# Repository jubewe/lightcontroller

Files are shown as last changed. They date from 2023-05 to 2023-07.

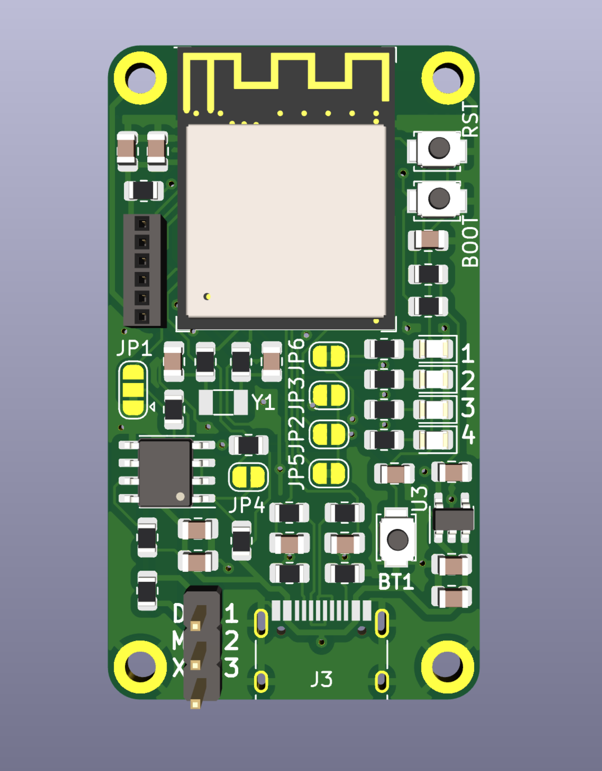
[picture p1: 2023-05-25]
pcb/pcb1.png

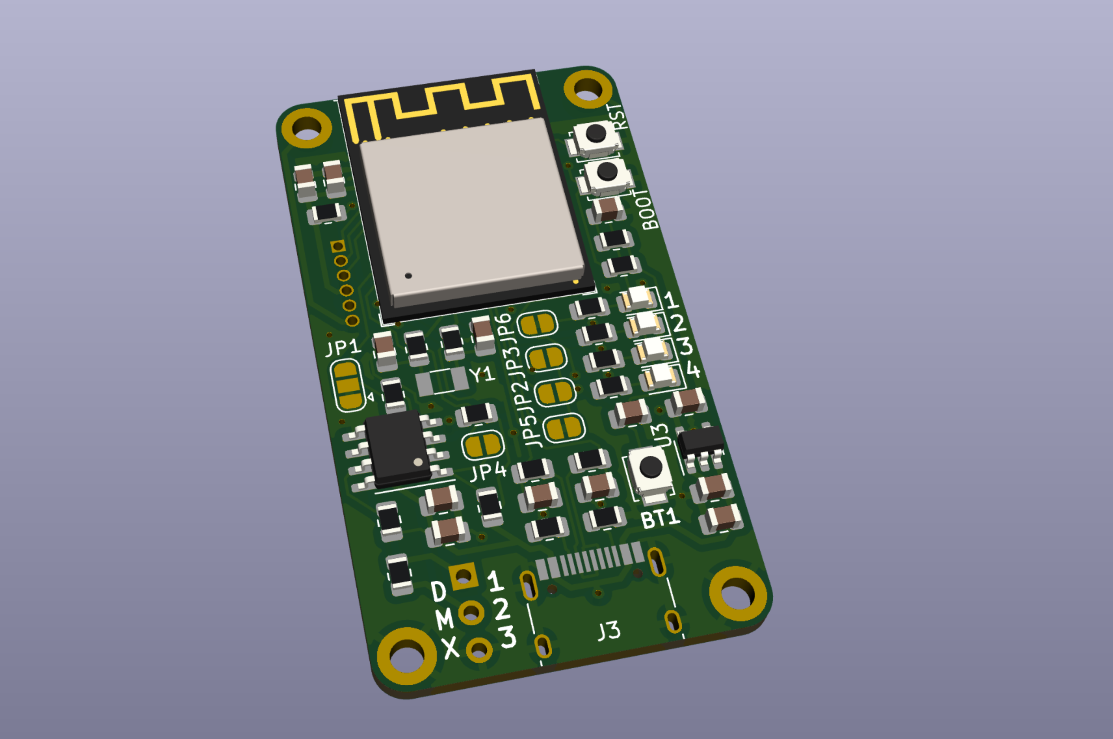
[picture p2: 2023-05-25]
pcb/pcb2.png

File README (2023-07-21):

--- 1.0 Einleitung ---

  Diese Software wurde von 2 Schülern der Schule / Bühnentechnik geschrieben und ist unter der Gnu General Public License (Version 3) lizenziert (https://www.gnu.org/licenses/gpl-3.0.en.html)

  GitHub Repository: https://github.com/jubewe/lightcontroller
  CAD Case: https://cad.onshape.com/documents/32544a06e8ec4764e1459a3b/w/4d291bb81697a02a01b341a5/e/0fd6ec4ab97829387aade676

--- 1.0.2 Verbindung ---
  Um den Lightcontroller bedienen zu können, verbinde dich per WLAN dem Gerät (am Handy Mobile Daten ausschalten):
  SSID:   lightcontroller
  PW:     password

  Nach erfolgreichem Verbinden, gehe auf http://192.168.4.1.
  Dort findest du das Webinterface für den Controller.

  Beim Abrufen der Seite wird anfangs der aktuelle Status der Lichter abgefragt und synchronisiert

--- 1.1 Gruppen von Lichtern ---

  Namen und Beschreibungen gesehen von Eingang Aula (Pausenhof)
  → Außen = Weiter von Mitte der Aula weg
  → Innen = Näher an Mitte der Aula

Syntax: 
* <Gruppe>: <Beschreibung>

* Bühne: Alle Lichter an Traverse
* Spots: Alle Spots vor der Bühne

* Links: Alle Lichter links der Mitte der Aula (inkl. Spots)
* Rechts: Alle Lichter rechts der Mitte der Aula (inkl. Spots)

# Bühne:
* Bühne Links: Alle Lichter links der Mitte der Traverse
* Bühne Rechts: Alle Lichter rechts der Mitte der Traverse

* Bühne Hinten: Alle Lichter auf hinterer Traverse
* Bühne Vorne: Alle Lichter auf vorderer Traverse

* Bühne Links Außen: Alle Lichter in Äußerster Linker Reihe
* Bühne Links Innen: Alle Lichter in Linker Mittlerer Reihe

* Bühne Rechts Außen: Alle Lichter in Äußerster Rechter Reihe
* Bühne Rechts Innen: Alle Lichter in Rechter Mittlerer Reihe

* Bühne Links Vorne: Alle Vorderen Lichter der Gruppe "Bühne Links"
* Bühne Links Hinten: Alle Hinteren Lichter der Gruppe "Bühne Links"

* Bühne Rechts Vorne: Alle Vorderen Lichter der Gruppe "Bühne Rechts"
* Bühne Rechts Hinten: Alle Hinteren Lichter der Gruppe "Bühne Rechts"

# Spots:
* Spots Links: Alle Spots links der Mitte der Aula
* Spots Rechts: Alle Spots rechts der Mitte der Aula

* Spots Oben: Alle oberen Spots
* Spots Unten: Alle unteren Spots

--- 1.2 DMX-Addressen ---

  Für jeden Scheinwerfer, egal ob RGB-LED oder nicht, sind je 6 Kanäle reserviert (für Kompatibilität von neuen LED Scheinwerfern)

  Da das DMX-Protokoll genutzt wird, kann jedem Kanal ein Wert von 0 bis 255 zugewiesen werden

  # Kanalbelegung der Kanäle (Normal): 
    dimm,0,0,0,0,0

  # Kanalbelegung der Kanäle (LED): 
  # → Werte der Kanäle der LEDs werden von der Website gedimmt
    rot,grün,blau,weiß,bernstein,uv

--- 1.2.2 Belegung der DMX-Addressen ---

Syntax: 
* <name>                   <dmx start>   <dmx end>

* Bühne Links Außen Hinten         1       6
* Bühne Links Innen Hinten         7       12
* Bühne Rechts Innen Hinten        13      18
* Bühne Rechts Außen Hinten        19      24
* Bühne Links Außen Vorne          25      30
* Bühne Links Innen Vorne          31      36
* Bühne Rechts Innen Vorne         37      42
* Bühne Rechts Außen Vorne         43      48

* Spot Links Oben                  49      54
* Spot Links Unten                 55      60
* Spot Rechts Oben                 61      66
* Spot Rechts Unten                67      72

--- 1.3 Presets ---

Es besteht die Möglichkeit, lokale Presets zu erstellen, die die Werte der Kanäle speichern.
Dies kann genutzt werden, um schnell zwischen Bühnenbildern (wie Rede und Musik) zu wechseln.
Sie werden aber nur lokal auf dem aktuellen Gerät gespeichert, können aber exportiert werden.
Wichtig: Keine Leerzeichen in Presetnamen!

--- 1.3.1 Speicherung der Presets ---

Format:
<dmx-start>,<r>,<g>,<b>,<w>,<a>,<u>,<dimm>,<fade>

--- 1.4 Known Bugs ---

- Der "flash" Effekt funktioniert nicht
- fade ist teilweise nicht stable -> reconnect oder restart
- DMX Output ist langsam/Latenz (evtl. neu flashen mit kleinerer "maxLights" Variable)

--- 1.5 Flashen der Controller (neue Firmware) ---

- mit VisualStudioCode und Platform.io Extension mit angepasster DMX-library
- Ordner "backend" für master (1x) aktuell hinten links über der Bühne (Leiter und langes USB-C <-> USB-A Kabel)
- Ordner "backend-receiver" für beliebig viele receiver Module (neue MAC Addressen müssen im master code für die Verbindung mit ESP-Now eingetragen werden)
- BOOT Button halten während USB-Eingesteckt wird (manchmal notwendig)

--- 1.6 Notizen zur Hardware/PCB ---

- Schaltplan und PCB-Layout in diesem git-repo (pcb Ordner)
- gerber Dateien für Nachbestellung bei jlcpcb unter "pcb/gerbers_REV1.1/gerbers.zip")
- das Quartz (Y1) und die beiden Kondensatoren (C12,C13) sowie R16 und R17 werden nicht benötigt
- genau Teileliste "parts.ods" mit Bestellnummern für LCSC

--- x.1 Sonstiges ---

Die Website frägt am Anfang den aktuellen Status der Lichter vom Master ab, die Werte überschreiben dann die aktuellen Werte

Arduino Lib espdmx:  https://github.com/Rickgg/ESP-Dmx
→ Example:  https://github.com/Rickgg/ESP-Dmx/blob/master/examples/RGB_DMX/RGB_DMX.ino#L10 

DMX Addresses:  https://www.thedmxwiki.com/dmx_basics/dmx_addresses

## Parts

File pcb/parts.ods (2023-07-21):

Source: | /home/johannes/Dokumente/lightcontroller/pcb/pcb.kicad_sch
Date: | Di 23 Mai 2023 16:28:15 CEST
Tool: | Eeschema 7.0.2-6a45011f42~172~ubuntu23.04.1
Generator: | /usr/share/kicad/plugins/bom_csv_grouped_by_value_with_fp.py
Component Count: | 57
Ref | Qnty | Value | Cmp name | Footprint | Description | LCSC #
C1, C6, C7, C9 | 4 | 100nF | C | Capacitor_SMD:C_0805_2012Metric | Unpolarized capacitor
C2, C8 | 2 | 10µF | C | Capacitor_SMD:C_0805_2012Metric | Unpolarized capacitor | C380331 (https://www.lcsc.com/product-detail/_CCTC-_C380331.html)
C3, C4 | 2 | 1µF | C | Capacitor_SMD:C_0805_2012Metric | Unpolarized capacitor | C303896 (https://www.lcsc.com/product-detail/_FH-Guangdong-Fenghua-Advanced-Tech-_C303896.html)
C5 | 1 | 22µF | C | Capacitor_SMD:C_0805_2012Metric | Unpolarized capacitor | C5674 (https://www.lcsc.com/product-detail/_Samsung-Electro-Mechanics-_C5674.html)
C10, C11 | 2 | 20p | C | Capacitor_SMD:C_0805_2012Metric | Unpolarized capacitor | C309037 (https://www.lcsc.com/product-detail/_CCTC-_C309037.html)
C12, C13 | 2 | 20p (DNP) | C | Capacitor_SMD:C_0805_2012Metric | Unpolarized capacitor | C309037 (https://www.lcsc.com/product-detail/_CCTC-_C309037.html)
D1, D2, D3, D4 | 4 | LED | LED | LED_SMD:LED_0805_2012Metric | Light emitting diode | any 0805 LED
H1, H2, H3, H4 | 4 | MountingHole_Pad | MountingHole_Pad | MountingHole:MountingHole_2.2mm_M2_DIN965_Pad_TopBottom | Mounting Hole with connection | -
J1 | 1 | XLR3 | XLR3 | Connector_PinHeader_2.54mm:PinHeader_1x03_P2.54mm_Vertical | XLR Connector, Male or Female, 3 Pins | -
J2 | 1 | Conn_01x06_Socket | Conn_01x06_Socket | Connector_PinSocket_1.27mm:PinSocket_1x06_P1.27mm_Vertical | Generic connector, single row, 01x06, script generated | -
J4, J5 | 2 | Conn_01x06_Socket | Conn_01x06_Socket | Connector_PinHeader_1.27mm:PinHeader_1x06_P1.27mm_Vertical | Generic connector, single row, 01x06, script generated | -
JP1, JP3, JP6 | 3 | Jumper_2_Open | Jumper_2_Open | Jumper:SolderJumper-2_P1.3mm_Open_RoundedPad1.0x1.5mm | Jumper, 2-pole, open | -
JP2 | 1 | Jumper_3_Bridged12 | Jumper_3_Bridged12 | Jumper:SolderJumper-3_P1.3mm_Bridged12_RoundedPad1.0x1.5mm | Jumper, 3-pole, pins 1+2 closed/bridged | -
JP4, JP5 | 2 | Jumper_2_Bridged | Jumper_2_Bridged | Jumper:SolderJumper-2_P1.3mm_Bridged_RoundedPad1.0x1.5mm | Jumper, 2-pole, closed/bridged | -
R1, R2 | 2 | 5.1k | R | Resistor_SMD:R_0805_2012Metric | Resistor
R3 | 1 | 100R | R | Resistor_SMD:R_0805_2012Metric | Resistor
R4 | 1 | 20k | R | Resistor_SMD:R_0805_2012Metric | Resistor | C4328 (https://www.lcsc.com/product-detail/_UNI-ROYAL-Uniroyal-Elec-_C4328.html)
R5 | 1 | 10-20k | R | Resistor_SMD:R_0805_2012Metric | Resistor
R6, R7, R8, R15 | 4 | 10k | R | Resistor_SMD:R_0805_2012Metric | Resistor
R9, R10 | 2 | 36R | R | Resistor_SMD:R_0805_2012Metric | Resistor
R11 | 1 | 10k (NC) | R | Resistor_SMD:R_0805_2012Metric | Resistor
R12, R13, R14, R18 | 4 | 2k | R | Resistor_SMD:R_0805_2012Metric | Resistor
R16, R17 | 2 | 0R (NC) | R | Resistor_SMD:R_0805_2012Metric | Resistor | C5140080 (https://www.lcsc.com/product-detail/_VO-_C5140080.html)
SW1 | 1 | SW_RESET | SW_Push | Button_Switch_SMD:SW_SPST_B3U-1000P-B | Push button switch, generic, two pins | C231329 (https://www.lcsc.com/product-detail/Tactile-Switches_Omron-Electronics-B3U-1000P_C231329.html)
SW2 | 1 | BUTTON | SW_Push | Button_Switch_SMD:SW_SPST_B3U-1000P-B | Push button switch, generic, two pins | C231329 (https://www.lcsc.com/product-detail/Tactile-Switches_Omron-Electronics-B3U-1000P_C231329.html)
SW3 | 1 | SW_BOOT | SW_Push | Button_Switch_SMD:SW_SPST_B3U-1000P-B | Push button switch, generic, two pins | C231329 (https://www.lcsc.com/product-detail/Tactile-Switches_Omron-Electronics-B3U-1000P_C231329.html)
U1 | 1 | ESP32-S2-MINI-1 | ESP32-S2-MINI-1 | Espressif:ESP32-S2-MINI-1 | ESP32-S2-MINI-1 and ESP32-S2-MINI-1U are two powerful, generic Wi-Fi MCU modules that have a rich set of peripherals. They are an ideal choice for a wide variety of application scenarios relating to Internet of Things (IoT), wearable electronics and smart home. | C3013906 (https://www.lcsc.com/product-detail/_Espressif-Systems-_C3013906.html)
U2 | 1 | XUNPU_TYPEC-304J-BCP16 | XUNPU_TYPEC-304J-BCP16 | My parts:XUNPU TYPEC-304J-BCP16 | USB-C connector | C2835315 (https://www.lcsc.com/product-detail/_XUNPU-_C2835315.html)
U3 | 1 | MAX485E | MAX485E | Package_SO:SOIC-8_3.9x4.9mm_P1.27mm | Half duplex RS-485/RS-422, 2.5 Mbps, ±15kV electro-static discharge (ESD) protection, no slew-rate, no low-power shutdown, with receiver/driver enable, 32 receiver drive kapacitity, DIP-8 and SOIC-8 | C5279041 (https://www.lcsc.com/product-detail/_TWGMC-_C5279041.html)
U4 | 1 | XC6220B331MR | XC6220B331MR | Package_TO_SOT_SMD:SOT-23-5 | 1A, Low Drop-out Voltage Regulator, Fixed Output 3.3V, SOT-23-5 | C3040644 (https://www.lcsc.com/product-detail/_TECH-PUBLIC-_C3040644.html)
Y1 | 1 | Crystal_Small | Crystal_Small | Crystal:Crystal_SMD_3215-2Pin_3.2x1.5mm | Two pin crystal, small symbol | C32346 (https://www.lcsc.com/product-detail/_Seiko-Epson-_C32346.html)

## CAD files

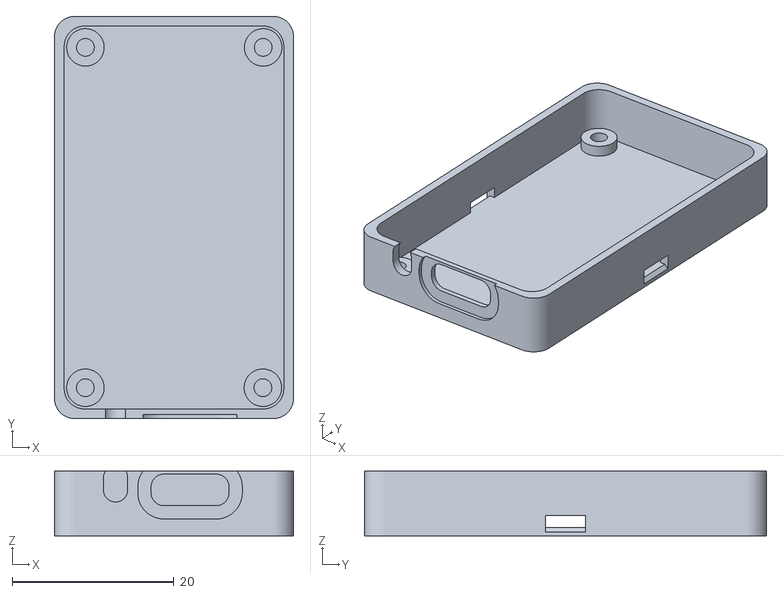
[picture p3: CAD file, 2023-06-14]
3d/CASE - BASE.stl
29.6 x 49.8 x 8.00

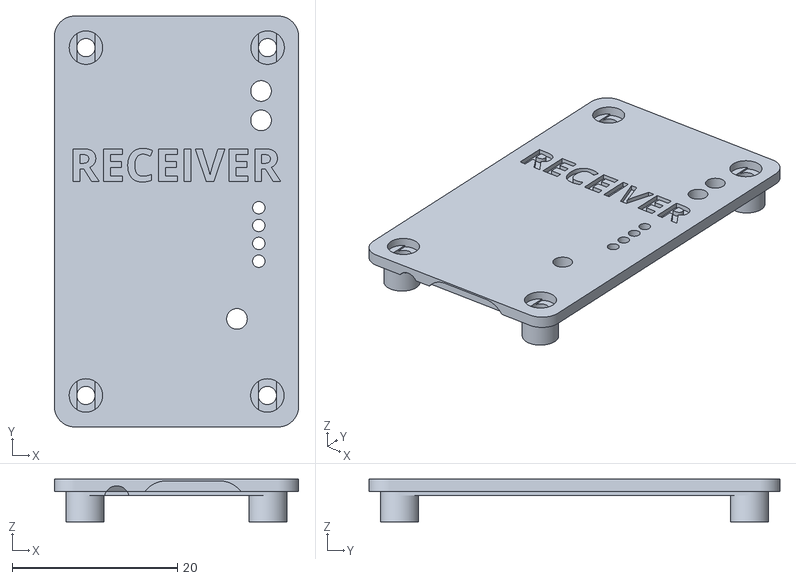
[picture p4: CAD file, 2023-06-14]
3d/CASE TOP - RECEIVER.stl
29.6 x 49.8 x 5.17

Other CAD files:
3d/CASE TOP - MASTER.stl

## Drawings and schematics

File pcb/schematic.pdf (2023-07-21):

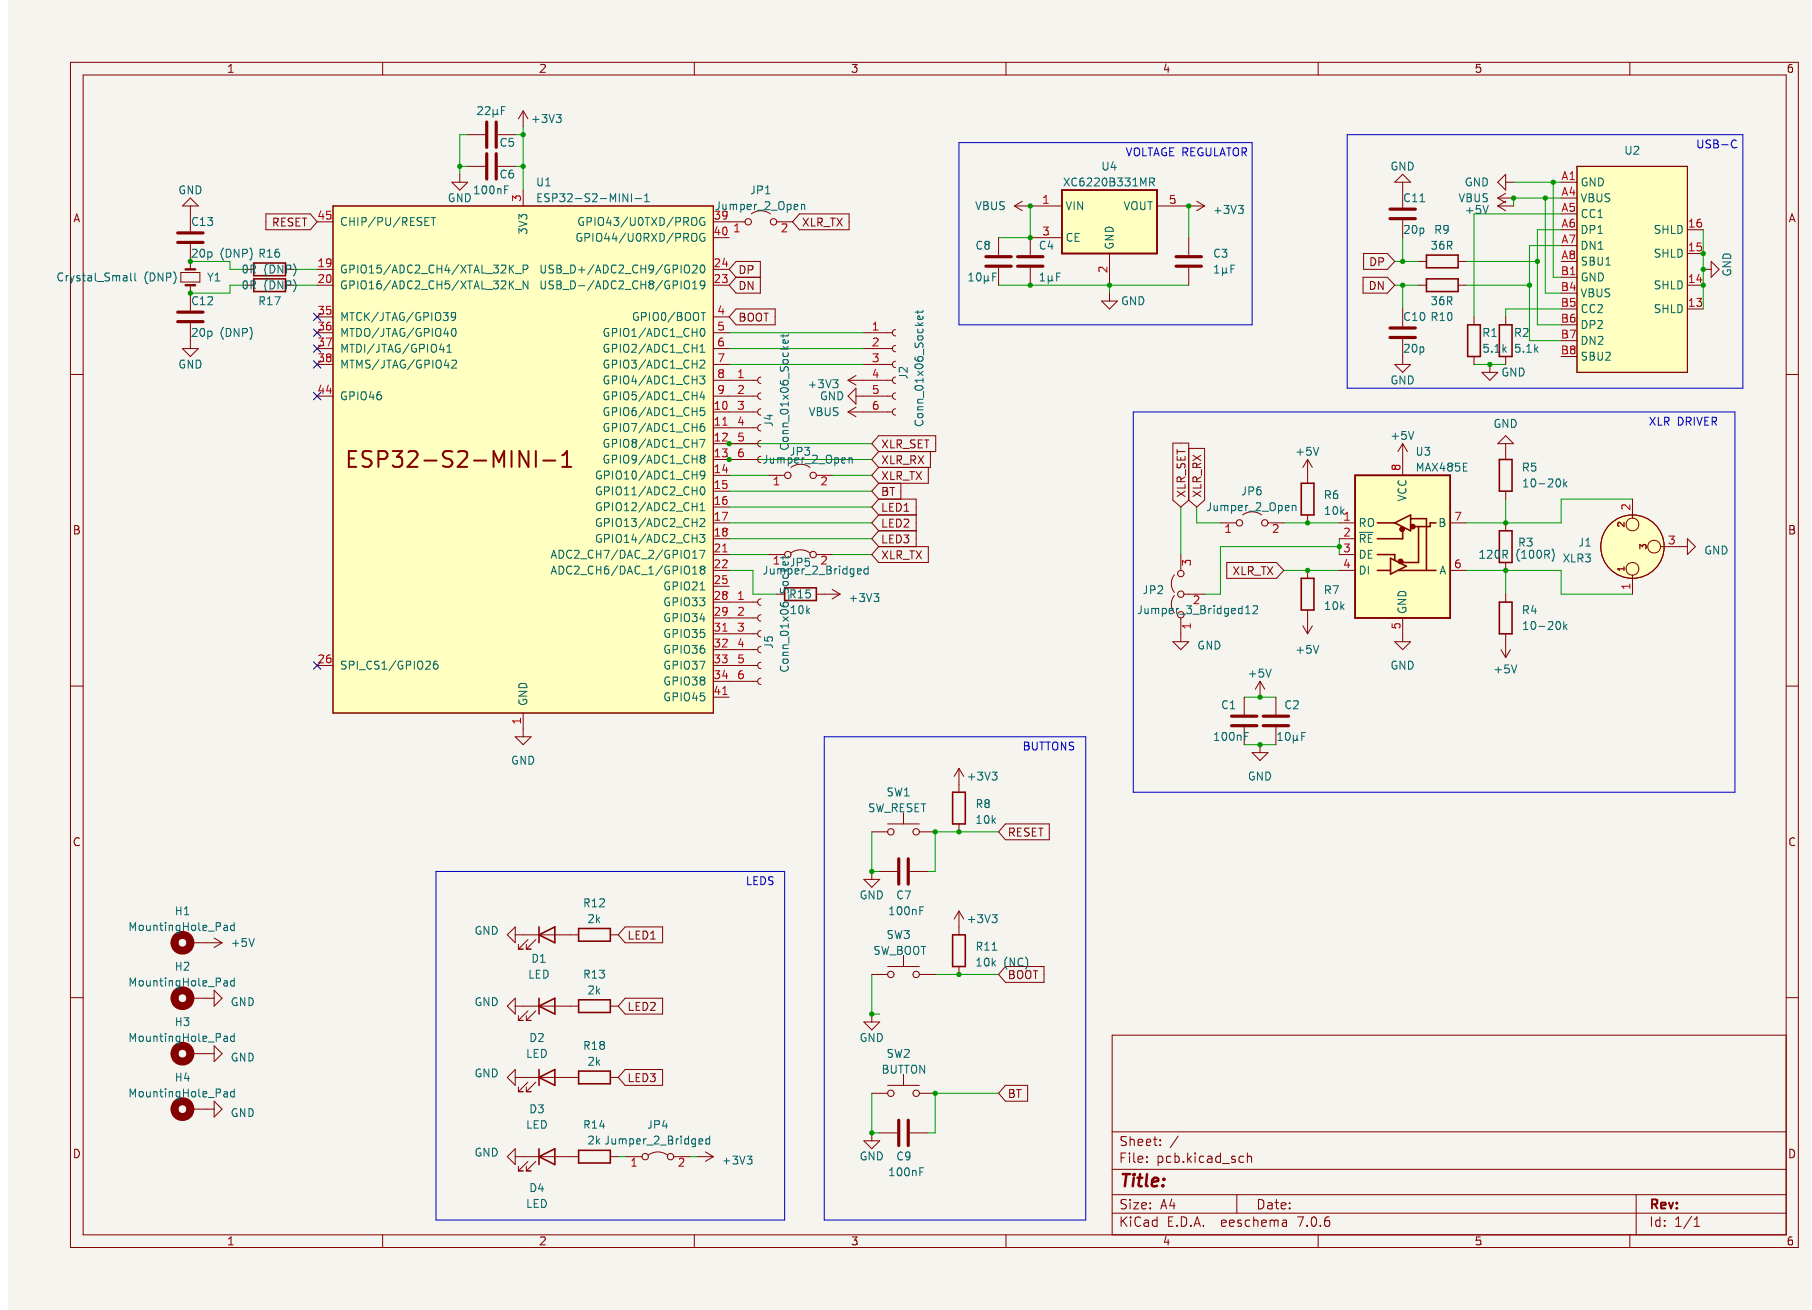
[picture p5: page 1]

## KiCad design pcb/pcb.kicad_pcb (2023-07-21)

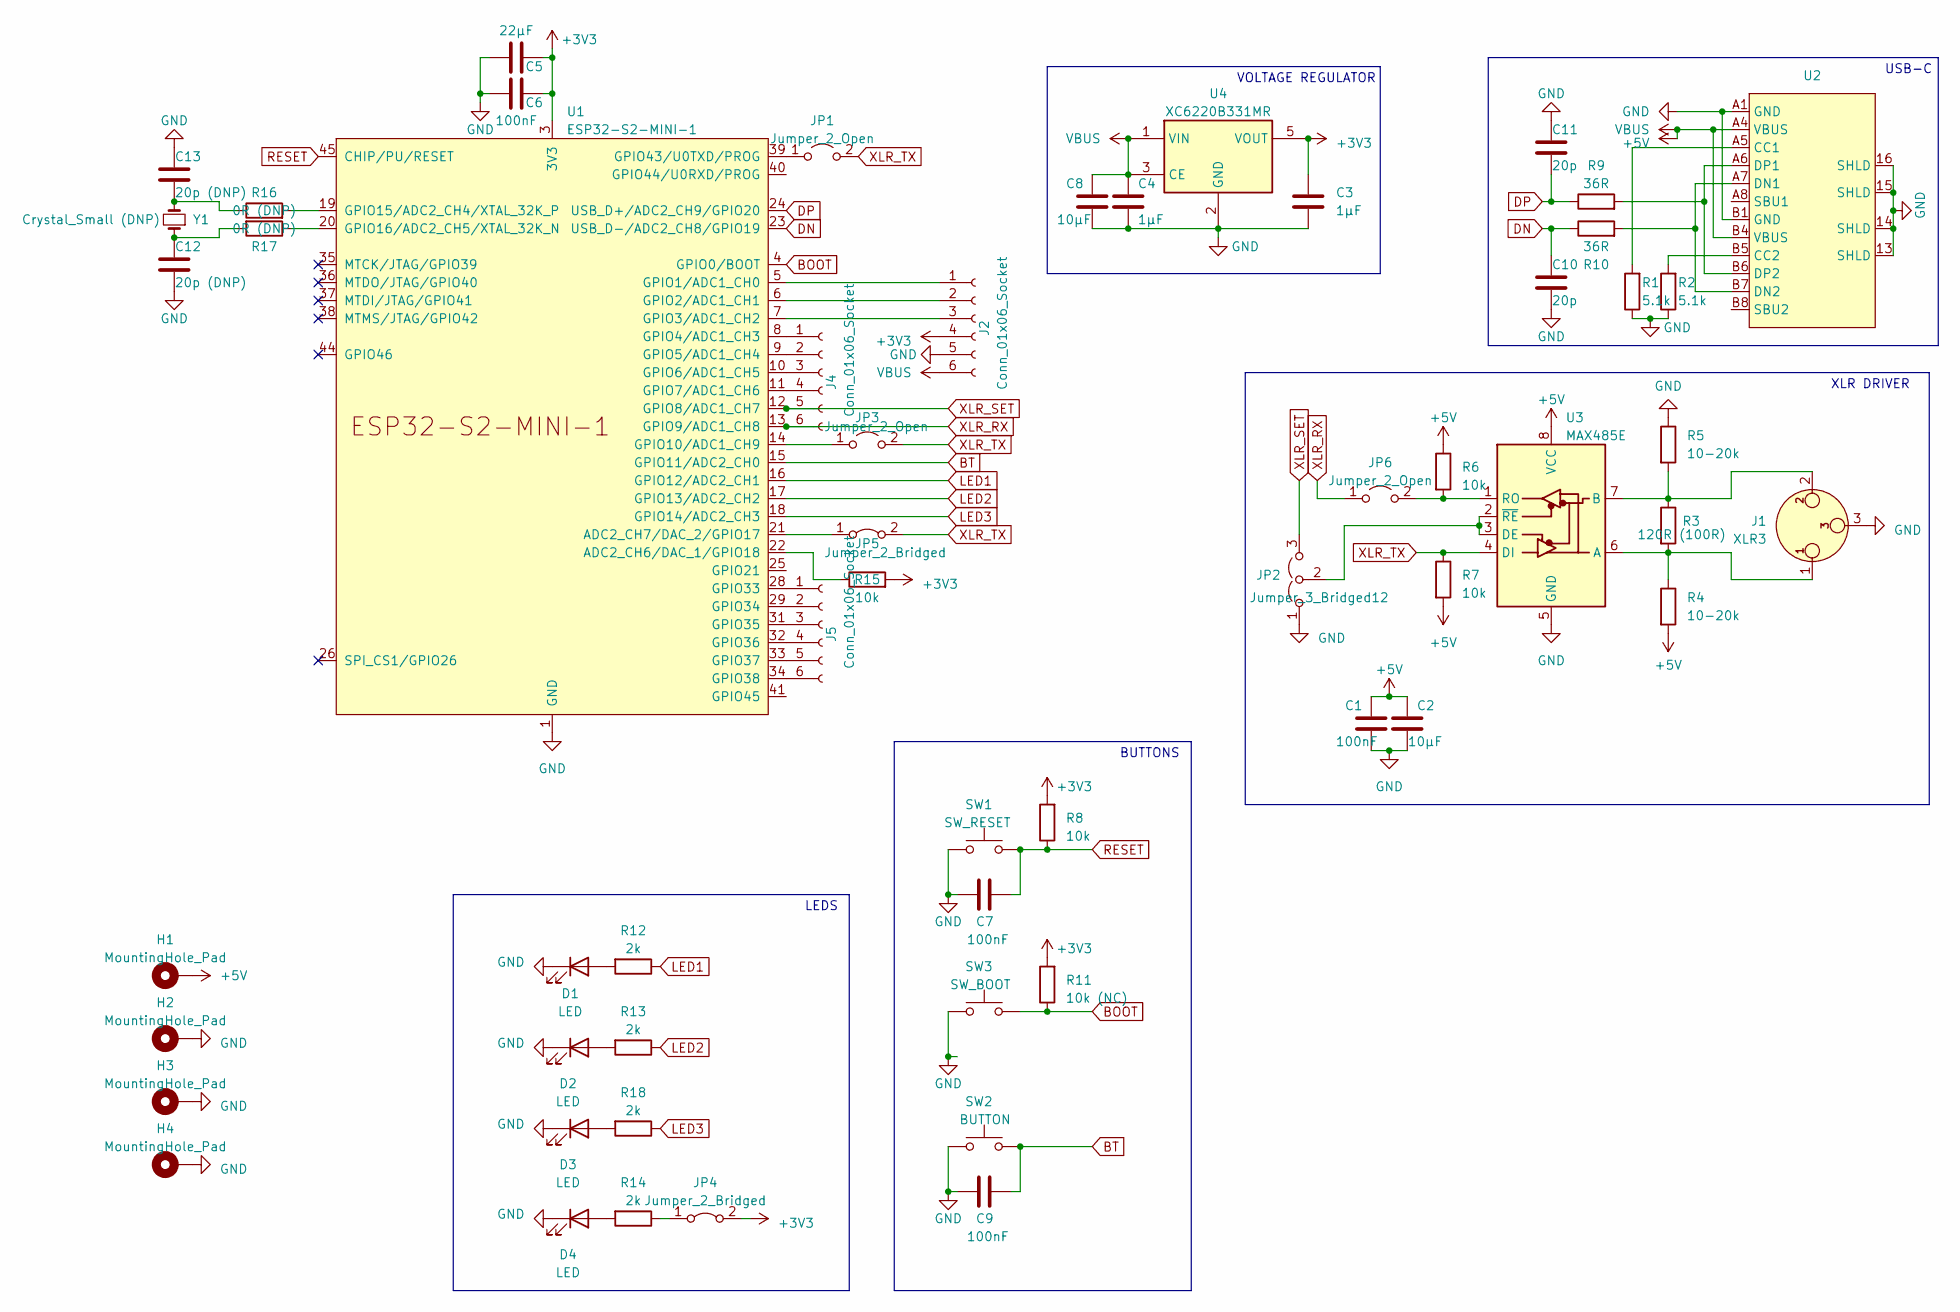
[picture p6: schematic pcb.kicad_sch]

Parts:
C1, C6, C7, C9: 100nF; C_0805_2012Metric
C2, C8: 10µF; C_0805_2012Metric
C3, C4: 1µF; C_0805_2012Metric
C5: 22µF; C_0805_2012Metric
C10, C11: 20p; C_0805_2012Metric
C12, C13: 20p (DNP); C_0805_2012Metric
D1, D2, D3, D4: LED; LED_0805_2012Metric
H1, H2, H3, H4: MountingHole_Pad; MountingHole_2.2mm_M2_DIN965_Pad_TopBottom
J1: XLR3; PinHeader_1x03_P2.54mm_Vertical
J2: Conn_01x06_Socket; PinSocket_1x06_P1.27mm_Vertical
J4, J5: Conn_01x06_Socket; PinHeader_1x06_P1.27mm_Vertical
JP1, JP3, JP6: Jumper_2_Open; SolderJumper-2_P1.3mm_Open_RoundedPad1.0x1.5mm
JP2: Jumper_3_Bridged12; SolderJumper-3_P1.3mm_Open_RoundedPad1.0x1.5mm
JP4, JP5: Jumper_2_Bridged; SolderJumper-2_P1.3mm_Bridged_RoundedPad1.0x1.5mm
R1, R2: 5.1k; R_0805_2012Metric
R3: 120R (100R); R_0805_2012Metric
R4, R5: 10-20k; R_0805_2012Metric
R6, R7, R8, R15: 10k; R_0805_2012Metric
R9, R10: 36R; R_0805_2012Metric
R11: 10k (NC); R_0805_2012Metric
R12, R13, R14, R18: 2k; R_0805_2012Metric
R16, R17: 0R (DNP); R_0805_2012Metric
SW1: SW_RESET; SW_SPST_B3U-1000P-B
SW2: BUTTON; SW_SPST_B3U-1000P-B
SW3: SW_BOOT; SW_SPST_B3U-1000P-B
U1: ESP32-S2-MINI-1
U2: XUNPU_TYPEC-304J-BCP16; XUNPU TYPEC-304J-BCP16
U3: MAX485E; SOIC-8_3.9x4.9mm_P1.27mm
U4: XC6220B331MR; SOT-23-5
Y1: Crystal_Small (DNP); Crystal_SMD_3215-2Pin_3.2x1.5mm

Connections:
+3V3: C3.1, C5.2, C6.2, J2.4, JP4.2 (B), R8.2, R11.2, R15.2, U1.3 (3V3), U4.5 (VOUT)
+5V: C1.1, C2.1, C4.1, C8.1, H1.1, J2.6, R4.2, R6.1, R7.2, U2.A4 (VBUS), U2.B4 (VBUS), U3.8 (VCC), U4.1 (VIN), U4.3 (CE)
DN: C10.1, R10.1, U1.23 (USB_D-/ADC2_CH8/GPIO19)
DP: C11.2, R9.1, U1.24 (USB_D+/ADC2_CH9/GPIO20)
GND: C1.2, C2.2, C3.2, C4.2, C5.1, C6.1, C7.2, C8.2, C9.2, C10.2, C11.1, C12.2, C13.1, D1.1 (K), D2.1 (K), D3.1 (K), D4.1 (K), H2.1, H3.1, H4.1, J1.3, J2.5, JP2.1 (A), R1.1, R2.1, R5.1, SW2.1, U1.1 (GND), U1.2 (GND), U1.30 (GND), U1.42 (GND), U1.43 (GND), U1.46 (GND), U1.47 (GND), U1.48 (GND), U1.49 (GND), U1.50 (GND), U1.51 (GND), U1.52 (GND), U1.53 (GND), U1.54 (GND), U1.55 (GND), U1.56 (GND), U1.57 (GND), U1.58 (GND), U1.59 (GND), U1.60 (GND), U1.61 (GND), U1.62 (GND), U1.63 (GND), U1.64 (GND), U1.65 (GND), U2.13 (SHLD), U2.14 (SHLD), U2.15 (SHLD), U2.16 (SHLD), U2.A1 (GND), U2.B1 (GND), U3.5 (GND), U4.2 (GND); also elsewhere on the board
LED1: R12.1, U1.16 (GPIO12/ADC2_CH1)
LED2: R13.1, U1.17 (GPIO13/ADC2_CH2)
LED3: R18.1, U1.18 (GPIO14/ADC2_CH3)
unnamed: C12.1, R17.2, Y1.1
unnamed: C13.2, R16.1, Y1.2
unnamed: D1.2 (A), R12.2
unnamed: D2.2 (A), R13.2
unnamed: D3.2 (A), R18.2
unnamed: D4.2 (A), R14.2
unnamed: J2.1, U1.5 (GPIO1/ADC1_CH0)
unnamed: J2.2, U1.6 (GPIO2/ADC1_CH1)
unnamed: J2.3, U1.7 (GPIO3/ADC1_CH2)
unnamed: J4.1, U1.8 (GPIO4/ADC1_CH3)
unnamed: J4.2, U1.9 (GPIO5/ADC1_CH4)
unnamed: J4.3, U1.10 (GPIO6/ADC1_CH5)
unnamed: J4.4, U1.11 (GPIO7/ADC1_CH6)
unnamed: J5.1, U1.28 (GPIO33)
unnamed: J5.2, U1.29 (GPIO34)
unnamed: J5.3, U1.31 (GPIO35)
unnamed: J5.4, U1.32 (GPIO36)
unnamed: J5.5, U1.33 (GPIO37)
unnamed: J5.6, U1.34 (GPIO38)
unnamed: JP1.1 (A), U1.39 (GPIO43/U0TXD/PROG)
unnamed: JP2.2 (C), U3.2 (~RE), U3.3 (DE)
unnamed: JP3.1 (A), U1.14 (GPIO10/ADC1_CH9)
unnamed: JP4.1 (A), R14.1
unnamed: JP5.1 (A), U1.21 (ADC2_CH7/DAC_2/GPIO17)
unnamed: JP6.2 (B), R6.2, U3.1 (RO)
unnamed: R15.1, U1.22 (ADC2_CH6/DAC_1/GPIO18)
unnamed: R16.2, U1.19 (GPIO15/ADC2_CH4/XTAL_32K_P)
unnamed: R17.1, U1.20 (GPIO16/ADC2_CH5/XTAL_32K_N)
unnamed: R1.2, U2.A5 (CC1)
unnamed: R2.2, U2.B5 (CC2)
unnamed: R10.2, U2.A7 (DN1), U2.B7 (DN2)
unnamed: R9.2, U2.A6 (DP1), U2.B6 (DP2)
unnamed: J1.1, R3.2, R4.1, U3.6 (A)
unnamed: J1.2, R3.1, R5.2, U3.7 (B)
XLR_RX: J4.6, JP6.1 (A), U1.13 (GPIO9/ADC1_CH8)
XLR_SET: J4.5, JP2.3 (B), U1.12 (GPIO8/ADC1_CH7)
XLR_TX: JP1.2 (B), JP3.2 (B), JP5.2 (B), R7.1, U3.4 (DI)

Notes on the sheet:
VOLTAGE REGULATOR
USB-C
LEDS
BUTTONS
XLR DRIVER

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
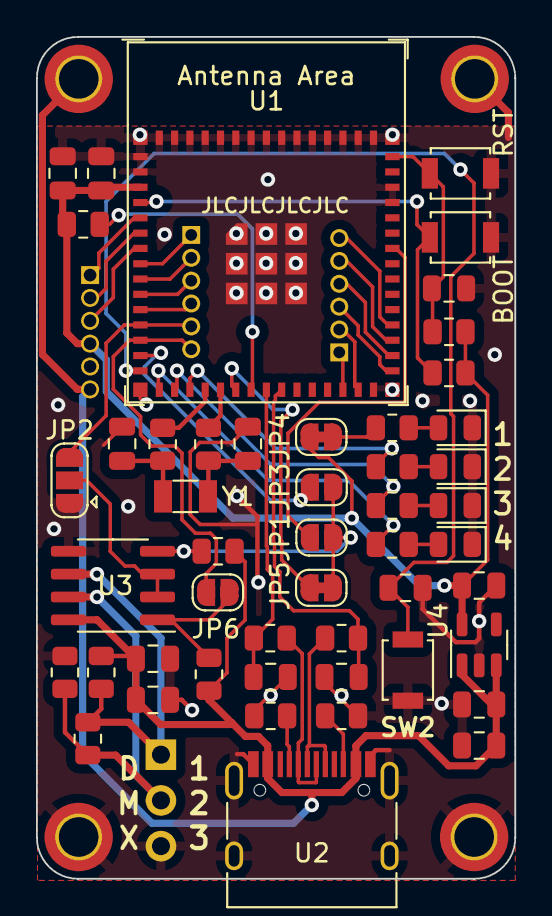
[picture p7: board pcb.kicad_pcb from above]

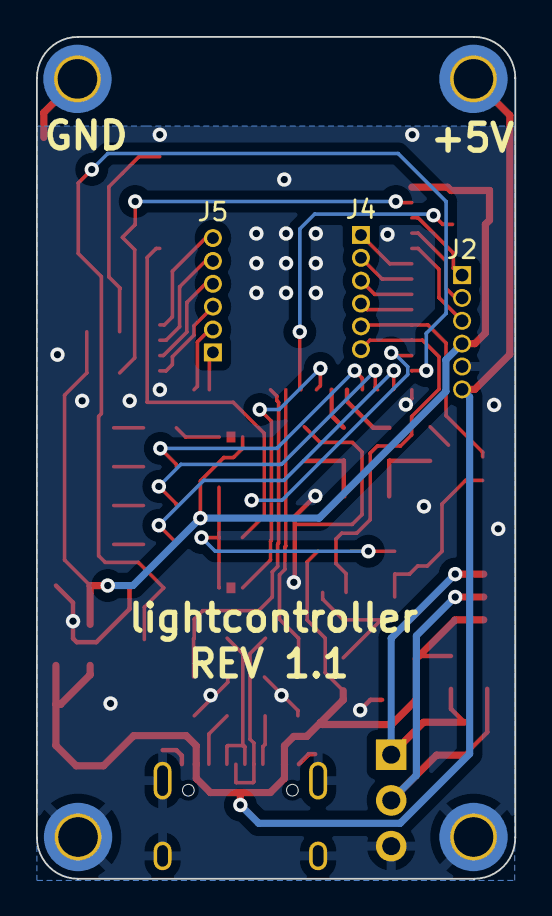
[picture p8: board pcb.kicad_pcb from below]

Board: 2 copper layers, 26.6 x 46.8 mm, 57 parts (2 on the bottom side), 48 nets.

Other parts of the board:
BOOT: SW_BOOT; SW_SPST_B3U-1000P-B
RST: SW_RESET; SW_SPST_B3U-1000P-B

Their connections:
GND: BOOT.1, RST.1; also elsewhere on the board

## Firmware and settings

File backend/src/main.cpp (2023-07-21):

/*
This code is a firmware running on a master ESP32 module that allows the user to control
multiple DMX-Lights (RGB + W + STROBE) using a web interface. It also includes the capability
to communicate with other receiver ESP32 modules to control lights that are not directly connected
to the master ESP32 hosting the web interface.
The firmware facilitates seamless coordination between the master and receiver modules,
enhancing the flexibility and convenience of controlling multiple DMX-Lights.
*/

// ESP-NOW code adapted from https://randomnerdtutorials.com/esp-now-esp32-arduino-ide/
// WebSocket code adapted from https://randomnerdtutorials.com/esp32-websocket-server-arduino/

#include <WiFi.h>
#include <AsyncTCP.h>
#include <ESPAsyncWebServer.h>
#include <ESPDMX.h>
#include <ESPmDNS.h>
#include <esp_now.h>
#include <Preferences.h>

Preferences preferences;

DMXESPSerial dmx;

// Replace with your network credentials
const char *ssid = "lightcontroller";
const char *password = "password";
const int wifi_channel = 1;
const int ssid_hidden = 0;

String config = "";

bool newData = false;

bool effect_flash = false;
bool effect_strobe = false;
int effect_speed = 100; // speed in ms between dmx write commands (only effects)
bool effect_strobe_state = false;
bool effect_flash_state = false;

// Add the MAC-Addresses of your receivers here
uint8_t broadcastAddressReceiver1[] = {0x58, 0xCF, 0x79, 0xB3, 0x90, 0xF8};
uint8_t broadcastAddressReceiver2[] = {0x58, 0xCF, 0x79, 0xB3, 0x92, 0x88};
uint8_t broadcastAddressReceiver3[] = {0x58, 0xCF, 0x79, 0xB3, 0x91, 0xEC};
esp_now_peer_info_t peerInfo1;
esp_now_peer_info_t peerInfo2;
esp_now_peer_info_t peerInfo3;

void initPeers()
{
    memcpy(peerInfo1.peer_addr, broadcastAddressReceiver1, 6);
    peerInfo1.channel = 0;
    peerInfo1.encrypt = false;
    memcpy(peerInfo2.peer_addr, broadcastAddressReceiver2, 6);
    peerInfo2.channel = 0;
    peerInfo2.encrypt = false;
    memcpy(peerInfo3.peer_addr, broadcastAddressReceiver3, 6);
    peerInfo3.channel = 0;
    peerInfo3.encrypt = false;

    // Add peer
    if (esp_now_add_peer(&peerInfo1) != ESP_OK)
    {
        // Serial.println("Failed to add peer 1");
    }
    if (esp_now_add_peer(&peerInfo2) != ESP_OK)
    {
        // Serial.println("Failed to add peer 2");
    }
    if (esp_now_add_peer(&peerInfo3) != ESP_OK)
    {
        // Serial.println("Failed to add peer 3");
    }
}

struct lightState
{
    int start_address;
    int red;
    int green;
    int blue;
    int white;
    int amber;
    int uv;
};

int fade = 0;

unsigned long previousMillisLED = 0;
unsigned long previousMillisEffect = 0;
int led_intv = 500;
int ledState = LOW;

#define redLEDPin 14
#define greenLEDPin 13
#define blueLEDPin 12

const int maxLights = 512/6;
lightState lightStates[maxLights];
lightState lightStatesOld[maxLights];
lightState DMX_Data;

int addrChanged[maxLights];
int numAddrChanged = 0;

void OnDataSent(const uint8_t *mac_addr, esp_now_send_status_t status)
{
    // Serial.print("Last Packet Send Status:");
    // Serial.println(status == ESP_NOW_SEND_SUCCESS ? "Delivery Success" : "Delivery Fail");
    if (status == ESP_NOW_SEND_FAIL)
    {
        digitalWrite(redLEDPin, HIGH);
    }
}

// Create AsyncWebServer object on port 80
AsyncWebServer server(80);
AsyncWebSocket ws("/ws");
AsyncWebSocketClient *globalClient = NULL;

// complete code in /frontend
const char index_html[] PROGMEM = R"rawliteral(<!-- Welcome to the Frontend --><!-- https://github.com/jubewe/lightcontroller --><!DOCTYPE html><html lang="en"><head><meta charset="UTF-8"><meta http-equiv="X-UA-Compatible"content="IE=edge"><meta name="viewport"content="width=device-width,initial-scale=1"><title>Lightcontroller</title></head><body><h3>Lightcontroller</h3><div id="lightcontrolsgroup"></div><div id="lightcontrols"></div></body><footer><h>This Controller was made by</h><a href="https://github.com/jubewe">Julian (Frontend)</a> <a href="https://github.com/jojo-06">Johannes (PCB + Backend)</a> <a href="https://github.com/jubewe/lightcontroller">Documentation (GitHub)</a></footer></html><script>const url=new URL(document.baseURI),splitter="---",presetAddressSplitter="-",presetChannelSplitter=",",presetEntrySplitter=";";let elementsLoaded;const lightConfig="Spot Links Außen Hinten;1;6;Bühne,Links,Bühne Links,Bühne Hinten,Bühne Außen,Bühne Links Außen,Bühne Links Hinten---Spot Links Innen Vorne;31;6;Bühne,Links,Bühne Links,Bühne Vorne,Bühne Innen,Bühne Links Innen,Bühne Links Vorne---Spot Rechts Innen Vorne;37;6;Bühne,Rechts,Bühne Rechts,Bühne Vorne,Bühne Innen,Bühne Rechts Innen,Bühne Rechts Vorne---Spot Rechts Außen Hinten;19;6;Bühne,Rechts,Bühne Rechts,Bühne Hinten,Bühne Außen,Bühne Rechts Außen,Bühne Rechts Hinten---Spot Links Oben;49;6;Spots,Spots Links,Spots Oben,Links---Spot Links Unten;55;6;Spots,Spots Links,Spots Unten,Links---Spot Rechts Oben;61;6;Spots,Spots Rechts,Spots Oben,Rechts---Spot Rechts Unten;67;6;Spots,Spots Rechts,Spots Unten,Rechts";console.debug("Loaded config",lightConfig);const RGBchannels=[["Red","r","#ff0000",0],["Green","g","#00ff00",0],["Blue","b","#0000ff",0],["White","w","#ffffff",255],["Amber","a","#ffbf00",0],["UV","u","#5f4b8b",0]],rangeInputMin=0,rangeInputMax=255,rangeInputDefault=0,fadeRangeMin=0,fadeRangeMax=30,fadeRangeDefault=0,fadeDefaultTime=1,fadeLiveDefaultTime=0,channelsPerRGBLight=6;let groups={},liveUpdate=!1,groupToggle=!0,channelsToggle=!0,lightStates={channels:{},groups:{},master:""},fullOn=0,fullOff=0,quickStates={fullOn:{_all:0},fullOff:{_all:0}},lights=lightConfig;lights.split("---").forEach((e=>{let t=e.split(";")[3];0!==(t?.length??0)&&t.split(",").forEach((t=>{groups[encodeURI(t)]||(groups[encodeURI(t)]=[]),groups[encodeURI(t)].push(e)}))})),lights=lights.split("---").filter((e=>e.length>0)).join("---"),console.debug("Groups",groups);class functions{static request=(e,t)=>new Promise(((n,o)=>{/^http(s)*:\/{2}/i.test(e)||(e=url.origin+e),t=t??{},fetch(e,t).then((e=>{n(e.body)})).catch(o)}));static submitConfig=e=>{this.request("/config",{headers:{plain:"string"!=typeof e?JSON.stringify(e):e},method:"POST"}).then((()=>{console.debug("POST Config Success")})).catch((e=>{console.error("POST Config error",e)}))};static getWhite=e=>"ffffff"===e.replace(/^#/,"").toLowerCase()?255:0;static hexToRGBParsed=e=>functions.hexToRGB(e);static hexToRGB=e=>{let t={};return e.replace(/^#/,"").match(/\w{2}/g).forEach(((e,n)=>t[["r","g","b"][n]]=parseInt(e,16))),t};static RGBToHex=(e,t,n,o)=>{let s="#";return s+=functions.pad2(Math.abs(e).toString(16)),s+=functions.pad2(Math.abs(t).toString(16)),s+=functions.pad2(Math.abs(n).toString(16)),s};static pad2=e=>/^\d$/.test(e)?`${parseInt(e)<10?"0":""}${e}`:`${e.length<2?"0":""}${e}`;static getValuesFromChannels=e=>{let t={};return RGBchannels.forEach((n=>{t[n[1]]=document.getElementById(`${e}-channels-${n[1]}`).value})),t};static appendValuesFromChannels=e=>{let t=functions.getValuesFromChannels(e),[n,o,s]=[t.r,t.g,t.b],l=functions.RGBToHex(n,o,s);return document.getElementById(`${e}-color`).value=l,l};static appendHexToChannels=(e,t)=>{let n=t??document.getElementById(`${e}-color`).value,o=functions.hexToRGBParsed(n),s={};return Object.keys(o).forEach((t=>{document.getElementById(`${e}-channels-${t}`).value=o[t],s[t]=o[t]})),s};static appendToChannels=(e,t)=>{Object.keys(t).forEach((n=>{document.getElementById(`${e}-channels-${n}`).value=t[n]}))};static parseWSUpdateMessage=(e,t,n,o,s,l,a,c,i)=>{let r=[e,...[e,n,o,s,l,a,c,1e3*(i??0)].slice(1,7).map((e=>Math.floor(parseInt(e)*(1-(t??0)/100)))),1e3*i];return[].concat(r,Array(8).slice(0,8-r.length))};static updateLight=(e,t,n,o,s,l,a,c,i)=>{if(0===e.length)return;let r=this.parseWSUpdateMessage(e,t,n,o,s,l,a,c,i);console.debug("WS Update RGB",r.join(";")),ws?.send(r.join(";"))};static parseWSUpdateMessagenoRGB(e,t,n){return[e,Math.floor(255*(1-t/100)),...[...Array(5)].map((e=>0)),1e3*n]}static updateLightnoRGB=(e,t,n)=>{0!==e.length&&(console.debug("WS Update Non-RGB",[e,Math.floor(255*(1-t/100)),...[...Array(5)].map((e=>0)),1e3*n].join(";")),ws?.send(this.parseWSUpdateMessagenoRGB(e,t,n).join(";")))};static updateLightVal=(e,t,n)=>{if(0===e.length)return;let o=t;Array.isArray(o)||(o=[...Array(6)].map((e=>t))),console.debug("WS Update Val",[e,...o,1e3*n].join(";"));ws?.send([e,...o,1e3*n].join(";"))};static quickButtonActive=e=>{e.classList.add("quickActionButton-active")};static quickButtonInactive=e=>{e.classList.remove("quickActionButton-active")};static getQuickState=(e,t)=>quickStates[e]?.[t]??0;static appendHeld=e=>{let t=quickStates[e()];if(!t?.heldActions)return;let n=[],o=[];t.heldActions.reverse().forEach((e=>{let t=e[0],s=e[1];function l(e,t){0===e[0].length||t.filter((t=>t[0].join(";")===e[0].join(";")))[0]||t.push(e)}l(t,n),l(s,o)})),n.forEach((e=>{functions.updateLight(...e)})),o.forEach((e=>{functions.updateLightnoRGB(...e)})),t.heldActions=[]};static disableElem=e=>{e.disabled=!0};static enableElem=e=>{e.removeAttribute("disabled")};static getAddrChanNum=e=>{let t=lights.split("---").filter((t=>t.split(";")[1]===e.toString()));return t[0]?.split(";")[2]};static getLightByAddr=e=>lights.split("---").filter((t=>t.split(";")[1]===e.toString()))[0];static updateGroups=(e,t,n,o)=>{document.getElementById("controlsGroup")&&(document.getElementById("controlsGroup-color").value=n,document.getElementById("controlsGroup-dimm").value=e??0,document.getElementById("controlsGroup-fade").value=t??0,functions.appendToChannels("controlsGroup",o))};static isRGB=e=>"6"===this.getAddrChanNum(e);static appendFromStrings=e=>{let t=e.split(";").map((e=>e.split(","))),n=[...["r","g","b","w","a","u"].map((e=>`channels-${e}`)),"dimm","fade"];t.forEach((e=>function(e){let t,[o,s,l,a,c,i,r,d,u]=e,p=o.split("-");if("string"==typeof o&&!/^\d$/.test(o))if("master"===o.split(":")[0])p=lights.split("---").map((e=>e.split(";")[1])),t="controlsGroupAll";else p=o.split(":").at(-1).split("-"),t="controlsGroup";let h=void 0!==(t??void 0)||functions.isRGB(o),f=t??`controls${o}`,m=n.map((e=>`${f}-${e}`)).map((e=>functions.getElementByID(e)));if(m.forEach(((t,n)=>{t&&(t.value=e[n+1])})),h){functions.appendValuesFromChannels(f);let e=p,t=functions.RGBToHex(s,l,a),n=functions.getValuesFromChannels(f);e.length>0&&(functions.append(e.map((e=>functions.getLightByAddr(e))),d??0,u??0,t,n),functions.append("master",d??0,u??0,t,n,"controlsGroup"),functions.updateGroups(d,u,t,n))}}(e)))};static getElementByID=e=>document.getElementById(e)??void 0;static convertToArray=e=>e?Array.isArray(e)?e:[e]:[];static append=(e,t,n,o,s,l)=>{functions.convertToArray(e).map((e=>{let a=e?.split(";")?.[1]??e,c=l??`controls${a}`;if(!document.getElementById(c))return console.error("could not find controls",a,e);let i=parseInt(e.split(";")[2])>1;document.getElementById(`${c}-dimm`).value=t??0,document.getElementById(`${c}-fade`).value=n??0,i&&(document.getElementById(`${c}-color`).value=o,functions.appendToChannels(c,s))}))};static addKeysToObjectSync=(e,t,n)=>{let o=functions.convertToArray(t),s=e;for(let e=0;e<o.length-1;e++){let t=o[e];t in s||(s[t]={}),s=s[t]}return s[o[o.length-1]]=n,e};static getKeyFromObjectSync=(e,t)=>{let n=functions.convertToArray(t),o=e;for(let e=0;e<n.length;e++){if(!o?.hasOwnProperty(n[e]))return;o=o[n[e]]}return o};static deleteKeyFromObjectSync=(e,t)=>{let n=functions.convertToArray(t),o=e;for(let e=0;e<n.length-1;e++){if(!(n[e]in o))return;o=o[n[e]]}return delete o[n[n.length-1]],e};static localStorage=class{static#e="l";static init=()=>{this.setStorage({presets:{}})};static initIfNonexistent=()=>{this.getStorage()||this.init()};static getStorage=()=>localStorage.getItem(this.#e)?JSON.parse(localStorage.getItem(this.#e)):null;static setStorage=e=>{localStorage.setItem(this.#e,JSON.stringify(e))};static getKey=e=>{let t=this.getStorage();return functions.getKeyFromObjectSync(t,e)};static setKey=(e,t)=>{this.initIfNonexistent();let n=this.getStorage(),o=functions.addKeysToObjectSync(n,e,t);this.setStorage(o)};static deleteKey=e=>{let t=this.getStorage(),n=functions.deleteKeyFromObjectSync(t,e);this.setStorage(n)};static emptyCache=()=>{functions.localStorage.setKey("cache",{})}};static getPresets=()=>this.localStorage.getKey(["presets"])??{};static setPreset=(e,t)=>this.localStorage.setKey(["presets",encodeURI(e)],t);static deletePreset=e=>this.localStorage.deleteKey(["presets",encodeURI(e)]);static getPreset=e=>this.localStorage.getKey(["presets",encodeURI(e)])}class scripts{static loadLights=()=>{lightConfig.split("---").forEach(((e,t)=>{let n=0===e.length,[o,s,l,a]=e.split(";"),c=parseInt(l)>1,i=document.createElement("div");if(n||(i.id=`controls${s}`),i.classList.add("controlsContainer"),n)return i.classList.add("empty"),document.querySelector("#lightcontrols").appendChild(i);let r=document.createElement("div");r.classList.add("controlsContainerTop");let d=document.createElement("div");d.classList.add("controlsContainerBottom");let u=document.createElement("h");u.classList.add("controlsTitle"),n||(u.innerText=o);let p=document.createElement("h");p.classList.add("controlsGroupTitle"),n||(p.innerText=a.split(",").join(", "));let h=elements.controlsColorInput(i.id),f=elements.controlsChannelInputs(i.id),m=elements.controlsDimmerInput(i.id),g=elements.controlsFadeInput(i.id);h.onchange=()=>{E(),functions.appendHexToChannels(i.id)},f.onchange=()=>{E(),functions.appendValuesFromChannels(i.id)},m.onchange=()=>{E()},g.onchange=()=>{E()};let S=document.createElement("button");function E(e){let t=m.querySelector(".controlsDimmerInput").value,n=g.querySelector(".controlsFadeInput").value,o=1===functions.getQuickState("_all","fullOn")||1===functions.getQuickState("_all","fullOff"),l=1===functions.getQuickState("_all","isHeld");if(!c)return lightStates.channels[s]=[s,...Array(6).map((e=>"")),t,n].join(","),l?void quickStates._all.heldActions.push([[],[[s],t,n]]):void(!e&&!liveUpdate||o||functions.updateLightnoRGB(s,t,n));let a=h.querySelector(".controlsColorInput").value,r=(functions.hexToRGBParsed(a),functions.getValuesFromChannels(i.id)),{r:d,b:u,g:p,w:f,a:S,u:E}=r;lightStates.channels[s]=[s,...Object.values({r:d,b:u,g:p,w:f,a:S,u:E}),t,n].join(","),l?quickStates._all.heldActions.push([[[s],t,...Object.values(r),n],[]]):!e&&!liveUpdate||o||functions.updateLight(s,t,...Object.values(r),n)}S.innerText="Update",S.classList.add("controlsSubmit"),S.onclick=()=>{E(!0)},[u,p].map((e=>r.appendChild(e))),[...c?[h,f]:[],m,g,S].forEach((e=>d.appendChild(e))),[r,d].map((e=>i.appendChild(e))),document.querySelector("#lightcontrols").appendChild(i)}))};static loadLightGroups=()=>{let e=document.createElement("div");e.classList.add("groupControlsContainer"),e.id="controlsGroup";let t=document.createElement("h");t.innerText="Group Controls",t.classList.add("controlsTitle");let n=document.createElement("select");n.classList.add("controlsSelector"),Object.keys(groups).forEach((e=>{let t=document.createElement("option");t.innerText=decodeURI(e),t.value=e,n.appendChild(t)}));let o=elements.controlsColorInput(e.id),s=elements.controlsChannelInputs(e.id),l=()=>`_group_${n.value}`,a=elements.controlsQuickActions(e.id,l,d),c=elements.controlsDimmerInput(e.id),i=elements.controlsFadeInput(e.id),r=document.createElement("button");function d(t,s,a,r){let d=o.querySelector(".controlsColorInput").value,u=c.querySelector(".controlsDimmerInput").value,p=i.querySelector(".controlsFadeInput").value,h=n.value;s&&functions.appendHexToChannels(e.id,d),a&&(d=functions.appendValuesFromChannels(e.id));let f=functions.getValuesFromChannels(e.id),m=1===functions.getQuickState(l(),"fullOn")||1===functions.getQuickState(l(),"fullOff"),g=1===functions.getQuickState(l(),"isHeld"),S=groups[h].filter((e=>parseInt(e.split(";")[2])>1)).map((e=>e.split(";")[1])),E=groups[h].filter((e=>1===parseInt(e.split(";")[2]))).map((e=>e.split(";")[1])),{r:b,g:v,b:y,w:C,a:k,u:L}=f;if(lightStates.groups[l()]=[`group:${l()}:${[...S,...E].join("-")}`,...Object.values({r:b,g:v,b:y,w:C,a:k,u:L}),u,p].join(","),g)return quickStates[l()].heldActions.push([[S,u,...Object.values(f),p],[E,u,p]]);r?(functions.updateLightVal(S,r[0],0),functions.updateLightVal(E,r[1],0)):!t&&!liveUpdate||m||(S.length>0&&functions.updateLight(S.join(","),u,...Object.values(f),p),E.length>0&&functions.updateLightnoRGB(E.join(","),u,p)),functions.append(groups[h],u,p,d,f)}r.innerText="Update",r.classList.add("controlsSubmit"),r.onclick=()=>{d(!0)},o.onchange=()=>{d(!1,!0,!1)},s.onchange=()=>{d(!1,!1,!0)},c.onchange=()=>{d()},i.onchange=()=>{d()},[t,n,o,s,a,c,i,r].forEach((t=>e.appendChild(t))),document.querySelector("#lightcontrolsgroup").appendChild(e)};static loadLightAll=()=>{let e=document.createElement("div");e.classList.add("groupControlsContainer"),e.id="controlsGroupAll";let t=document.createElement("h");t.innerText="Master Controls",t.classList.add("controlsTitle");let n=elements.controlsColorInput(e.id),o=elements.controlsChannelInputs(e.id),s=()=>"_all",l=elements.controlsQuickActions(e.id,s,r),a=elements.controlsDimmerInput(e.id),c=elements.controlsFadeInput(e.id),i=document.createElement("button");function r(t,o,s,l){let i=n.querySelector(".controlsColorInput").value,r=a.querySelector(".controlsDimmerInput").value,d=c.querySelector(".controlsFadeInput").value;o&&functions.appendHexToChannels(e.id,i),s&&(i=functions.appendValuesFromChannels(e.id));let u=functions.getValuesFromChannels(e.id),p=1===functions.getQuickState("_all","fullOn")||1===functions.getQuickState("_all","fullOff"),h=1===functions.getQuickState("_all","isHeld"),f=lights.split("---").filter((e=>parseInt(e.split(";")[2])>1)).map((e=>e.split(";")[1])),m=lights.split("---").filter((e=>1===parseInt(e.split(";")[2]))).map((e=>e.split(";")[1])),{r:g,g:S,b:E,w:b,a:v,u:y}=u;if(lightStates.master=[`master:${[...f,...m].join("-")}`,...Object.values({r:g,g:S,b:E,w:b,a:v,u:y}),r,d].join(","),h)return
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
void loop()
{
    ws.cleanupClients();
    unsigned long currentMillis = millis();
    if (newData == true)
    {
        digitalWrite(blueLEDPin, HIGH);
        outputDMX();
        digitalWrite(blueLEDPin, LOW);
        digitalWrite(redLEDPin, LOW);

        newData = false;
    }
    if (currentMillis - previousMillisLED >= led_intv)
    {
        previousMillisLED = currentMillis;
        if (ledState == LOW)
        {
            ledState = HIGH;
        }
        else
        {
            ledState = LOW;
        }
        digitalWrite(greenLEDPin, ledState);
    }
    if (currentMillis - previousMillisEffect >= 100)
    {
        if (effect_strobe == true)
        {
            for (int i = 0; i < maxLights; i++)
            {
                if (lightStates[i].start_address != 0)
                {
                    int r;
                    int g;
                    int b;
                    int am;
                    int uv;
                    if (effect_strobe_state == 0)
                    {
                        int r_change = random(0, 2);  // Random value to determine if r should be at full brightness
                        int g_change = random(0, 2);  // Random value to determine if g should be at full brightness
                        int b_change = random(0, 2);  // Random value to determine if b should be at full brightness
                        int am_change = random(0, 2); // Random value to determine if am should be at full brightness
                        int uv_change = random(0, 2); // Random value to determine if uv should be at full brightness

                        r = (r_change == 1) ? random(0, 256) : 0;
                        g = (g_change == 1) ? random(0, 256) : 0;
                        b = (b_change == 1) ? random(0, 256) : 0;
                        am = (am_change == 1) ? random(0, 256) : 0;
                        uv = (uv_change == 1) ? random(0, 256) : 0;
                    }

                    effect_strobe_state = !effect_strobe_state;

                    int addr = lightStates[i].start_address;
                    dmx.write(addr, r);
                    dmx.write(addr + 1, g);
                    dmx.write(addr + 2, b);
                    dmx.write(addr + 3, 0);
                    dmx.write(addr + 4, am);
                    dmx.write(addr + 5, uv);
                    dmx.update();

                    DMX_Data.start_address = addr;
                    DMX_Data.red = r;
                    DMX_Data.green = g;
                    DMX_Data.blue = b;
                    DMX_Data.white = 0;
                    DMX_Data.amber = am;
                    DMX_Data.uv = uv;
                    esp_now_send_DMX();
                }
            }
        }

        else if (effect_flash == true)
        {
            for (int i = 0; i < 50; i++)
            {
                if (lightStates[i].start_address != 0)
                {
                    int addr = lightStates[i].start_address;
                    dmx.write(addr, 0);
                    dmx.write(addr + 1, 0);
                    dmx.write(addr + 2, 0);
                    dmx.write(addr + 4, 0);
                    dmx.write(addr + 5, 0);

                    DMX_Data.start_address = addr;
                    DMX_Data.red = 0;
                    DMX_Data.green = 0;
                    DMX_Data.blue = 0;
                    DMX_Data.amber = 0;
                    DMX_Data.uv = 0;
                    if (effect_flash_state)
                    {
                        dmx.write(addr + 3, 255);
                        DMX_Data.white = 255;
                        delay(100);
                    }
                    else
                    {
                        dmx.write(addr + 3, 0);
                        DMX_Data.white = 0;
                        delay(50);
                    }
                    effect_flash_state = !effect_flash_state;

                    dmx.update();

                    esp_now_send_DMX();

                }
            }
        }
    }
}

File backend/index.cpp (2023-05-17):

// Yoinked from https://github.com/Rickgg/ESP-Dmx/blob/master/examples/RGB_DMX/RGB_DMX.ino#L10

#include <Arduino.h>
#include <ESPDMX.h>
#include <ESP8266WiFi.h>
#include <ESP8266WiFiMulti.h>
#include <WebSocketsServer.h>
#include <ESP8266WebServer.h>
#include <ESP8266mDNS.h>

// WiFi network settings
const char* ssid     = "SSID";
const char* password = "password";

DMXESPSerial dmx;
ESP8266WiFiMulti WiFiMulti;
ESP8266WebServer server = ESP8266WebServer(80);
WebSocketsServer webSocket = WebSocketsServer(81);

void webSocketEvent(uint8_t num, WStype_t type, uint8_t * payload, size_t lenght) {
    switch(type) {
        case WStype_DISCONNECTED:
            Serial.println("[WS] Client Disconnected");
            break;
        case WStype_CONNECTED:
            Serial.println("[WS] Client connected");
            // send message to client
            webSocket.sendTXT(num, "Connected");
            break;
        case WStype_TEXT: 
            // # is the start for this data       
            if(payload[0] == '#') {
                // data received is comma separated, thats why we do pEnd+1 to start next value
                char * pEnd;
                uint32_t addresses = strtol ((const char *) &payload[1],&pEnd,16);
                uint32_t dimm = strtol ((const char *) pEnd+1,&pEnd,16);
                uint32_t red = strtol ((const char *) pEnd+1,&pEnd,16);
                uint32_t green = strtol ((const char *) pEnd+1,&pEnd,16);
                uint32_t blue = strtol ((const char *) pEnd+1,&pEnd,16);
                uint32_t white = strtol ((const char *) pEnd+1,&pEnd,16);
                uint32_t strobe = strtol ((const char *) pEnd+1,&pEnd,16);
                // write to DMX bus
                
                
                // split addresses and write dimm, rgb, white and strobe for each one
                addresses.split("")
                // ... {
                dmx.write(address, dimm);
                dmx.write(address+1, red);
                dmx.write(address+2, green);
                dmx.write(address+3, blue);
                dmx.write(address+4, white);
                dmx.write(address+5, strobe);
                // }
                dmx.update();
            }
            break;
    }
}

void setup() {
    Serial.begin(115200);
    Serial.println();

    // connect to WiFi 
    WiFi.hostname("rgbdmx");
    WiFi.mode(WIFI_STA);
    WiFi.begin(ssid, password);
    // wait for connection to be established
    while(WiFi.waitForConnectResult() != WL_CONNECTED){
      WiFi.begin(ssid, password);
      Serial.println("WiFi connection failed, retrying.");
      delay(500);
    }

    // start webSocket server
    webSocket.begin();
    webSocket.onEvent(webSocketEvent);

    if(MDNS.begin("rgbdmx")) {
        Serial.println("MDNS responder started");
    }

    // handle index
    server.on("/", []() {
        // send index.html
        server.send(200, "text/html", "<html><head><script>var connection = new WebSocket('ws://'+location.hostname+':81/', ['arduino']);connection.onopen = function () {  connection.send('Connect ' + new Date()); }; connection.onerror = function (error) {    console.log('WebSocket Error ', error);}; connection.onmessage = function (e) {  console.log('Server: ', e.data);}; id_array= new Array(\"addr\",\"r\",\"g\",\"b\"); values=new Array(id_array.length);  function prepareVar(id,position) {  for (i = 0; i < id_array.length; i++) {   var a = parseInt(document.getElementById(id_array[i]).value).toString(16);   if(a.length < 2) { a = '0' + a; }   values[i]=a; } sendVars(); }    function sendVars() { var data = '#'+values; console.log('Data: ' + data); connection.send(data); }  </script></head><body>LED Control:<br/><br/> <form> Starting address: <input id=\"addr\" type=\"number\" placeholder=\"1\" min=\"0\" max=\"512\" step=\"1\" onchange=\"prepareVar('addr',0);;\" /><br/> R: <input id=\"r\" type=\"range\" min=\"0\" max=\"255\" step=\"1\" onchange=\"prepareVar('r',1);\" oninput=\"this.form.r_in.value=this.value\" /><input id=\"r_in\" type=\"number\" min=\"0\" max=\"255\" step=\"1\" onchange=\"prepareVar('r',1);\" oninput=\"this.form.r.value=this.value\" /><br/> G: <input id=\"g\" type=\"range\" min=\"0\" max=\"255\" step=\"1\" onchange=\"prepareVar('g',2);\" oninput=\"this.form.g_in.value=this.value\" /><input id=\"g_in\" type=\"number\" min=\"0\" max=\"255\" step=\"1\" onchange=\"prepareVar('g',2);\" oninput=\"this.form.g.value=this.value\" /><br/> B: <input id=\"b\" type=\"range\" min=\"0\" max=\"255\" step=\"1\" onchange=\"prepareVar('b',3);\" oninput=\"this.form.b_in.value=this.value\" /><input id=\"b_in\" type=\"number\" min=\"0\" max=\"255\" step=\"1\" onchange=\"prepareVar('b',3);\" oninput=\"this.form.b.value=this.value\" /><br/> </form></body></html> ");
    });

    server.begin();
    MDNS.addService("http", "tcp", 80);
    MDNS.addService("ws", "tcp", 81);

    dmx.init(512); // initialize with bus length
 
    Serial.print("IP address: ");
    Serial.println(WiFi.localIP());
    Serial.print("RSSI: ");
    Serial.print(WiFi.RSSI());
    Serial.println(" dBm");
}

void loop() {
    webSocket.loop();
    server.handleClient();
}
